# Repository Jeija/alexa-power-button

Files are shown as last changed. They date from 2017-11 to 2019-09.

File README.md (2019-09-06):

# Alexa / Dash Button = PC power button
If you like to hide your desktop computer case so that it's not in the way, you probably know that it can be quite annoying to have to press the power button in an uncomfortable location every time you want to turn on your PC. `alexa-power-button` solves this by enabling you to use both voice commands for Amazon's digital assistant "Alexa" and/or an Amazon Dash Button to start your computer.

## Hardware
`alexa-power-button` doesn't use Wake on LAN so that you can save energy by turning off all of the attached network equipment apart from a single WiFi router in your home. Instead, the only additional active device is a small ESP32-based PCB inside the computer case that can be programmed and powered using the mainboard's internal USB connectors. Most mainboards can charge phones and other USB devices while the PC is turned off, and this current is more than enough to power the ESP32. The PCB contains n-channel MOSFETs that can be used to pull the power / reset button data line low. This assumes that the power / reset button input of the mainboard consists of an active-low input pin with a positive bias voltage. This pin should then be connected to the MOSFET's drain.

The KiCad design files (schematic, PCB layout) are provided in `hardware`.

## Dash Button Setup
* Use the Amazon App to configure the dash button
* In the last step, don't select which of the products in the list to order
* Press the dash button and use wireshark or similar tools to get the button's MAC address
* In the `firmware` directory: Execute `idf.py menuconfig` and enter the Dash Button's MAC Address in `Alexa Power Button --> Dash Button MAC Address` (including colons)

After flashing the firmware, the ESP32 will capture all WiFi traffic and check if source or destination address of the IEEE 802.11 header match the provided Dash Button MAC address.

## Alexa Skill + AWS MQTT / Lambda Setup
* Follow some of the [commonly available](https://www.hackster.io/darian-johnson/diy-smart-lamp-controlled-by-toggle-switch-and-alexa-7de243) [tutorials](https://developer.amazon.com/blogs/post/Tx4WG410EHXIYQ/five-steps-before-developing-a-smart-home-skill) on how to create an Alexa Skill, set up a Lambda function and set up AWS IoT for MQTT
* Make sure to select Payload Version `v2 (legacy)` when creating the Alexa Skill
* Upload the Lambda function. If you have the AWS CLI set up, you can use the Makefile provided in `aws` to upload and test the code.
* Add `THING_ENDPOINT` (AWS IoT HTTPS REST API endpoint host, see the thing's Interact page in AWS IoT) and `MQTT_BASE_TOPIC` (prefix for MQTT topic, e.g. `myhome/mypc`) as environment variables for the Lambda function
* Get your device private key and device certificate from AWS IoT and copy them to `firmware/main/certs` as `private.pem.key` and `certificate.pem.crt` respectively. See [esp-idf's AWS IoT documentation](https://github.com/espressif/esp-idf/tree/master/examples/protocols/aws_iot) for details.
* Confgiure the firmware: Run `idf.py menuconfig` in `firmware` and add your WiFi SSID and password in `Alexa Power Button`. Configure your (arbitrary but unique) AWS IoT Client ID and add the same MQTT base topic as specified in your Lambda function environment variable. Under `Component Config --> Amazon Web Services IoT Platform`, add your AWS IoT HTTPS REST API endpoint host, see the thing's Interact page on AWS IoT.
* Flash the firmware. If errors occur while connecting to AWS IoT, see [the documentation in esp-idf](https://github.com/espressif/esp-idf/tree/master/examples/protocols/aws_iot) for some common problems.

## Flash the firmware
* Use `idf.py menuconfig` in `firmware` to configure your python executable, serial port and flasher baud rate
* `alexa-power-button` uses the usual esp-idf CMake build system and workflow. Run `idf.py all` and `idf.py flash` in `firmware` in order to compile and flash the firmware to your ESP32 board.

## Attribution
* ESP32 schematic symbol and footprint: [adamjvr's ESP32-kiCAD-Footprints
](https://github.com/adamjvr/ESP32-kiCAD-Footprints)
* Alexa Skill Lambda function validation (`aws/validation.js`): [Amazon's alexa-smarthome-validation](https://github.com/alexa/alexa-smarthome-validation)
* ESP32 code: Roughly based on esp-idf's [AWS IoT Subscribe/Publish Example](https://github.com/espressif/esp-idf/tree/master/examples/protocols/aws_iot/subscribe_publish)

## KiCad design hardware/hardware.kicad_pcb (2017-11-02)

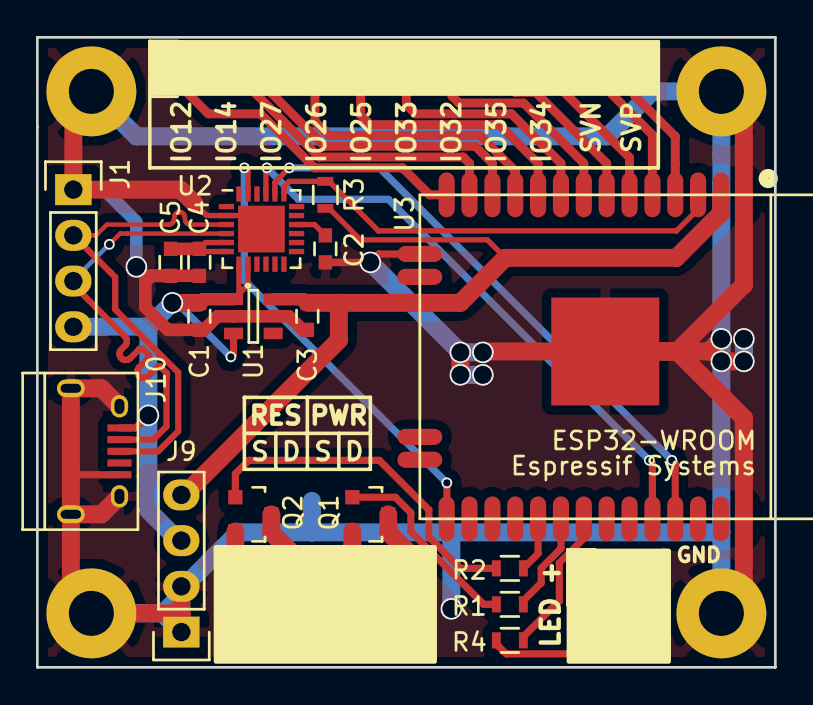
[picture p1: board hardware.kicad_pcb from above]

Board: 2 copper layers, 41.0 x 35.0 mm, 24 parts (0 on the bottom side), 33 nets.

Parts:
C1, C3: 1u; C_0603
C2, C4: 4.7u; C_0603
C5: 100n; C_0603
J1: USB; Pin_Header_Straight_1x04
J2: PWRLED; Pin_Header_Straight_1x02
J3: GPIO; Pin_Header_Straight_1x11
J4, J7: PWRSW; Pin_Header_Straight_2x01
J5, J8: RSTSW; Pin_Header_Straight_2x01
J6: PWRLED; Pin_Header_Straight_2x01
J9: Conn_01x04; Pin_Header_Straight_1x04
J10: USB_OTG; USB_Micro-B
Q1, Q2: IRLML 6344; SOT-23
R1, R2: 1K; R_0603
R3: 12K; R_0603
R4: 10K; R_0603
U1: TLV70033; SOT-23-5
U2: CP2104; QFN-24-1EP_4x4mm_Pitch0.5mm
U3: ESP32-WROOM

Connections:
+3V3: C3.1, J9.4, R3.1, U1.5, U3.2
+5V: C1.1, J1.4, J9.3, J10.1, U1.1, U1.3, U2.7, U2.8
/ESP_EN: R3.2, U2.19, U3.3
/ESP_RXD: U2.21, U3.34
/ESP_TXD: U2.20, U3.35
/PWRLED: R4.1, U3.31
/PWRSW: R1.2, U3.30
/RSTSW: R2.2, U3.29
/USB_D+: J1.2, J10.3, U2.3
/USB_D-: J1.3, J10.2, U2.4
/~ESP_FLASH: U2.23, U3.25
GND: C1.2, C2.2, C3.2, C4.2, C5.2, J1.1, J9.1, J9.2, J10.5, J10.6, U1.2, U2.2, U2.25, U3.1, U3.15, U3.38, U3.39
unnamed: C2.1, U2.16
unnamed: C4.1, C5.1, U2.5, U2.6
unnamed: J2.1, J6.2, R4.2
unnamed: J2.2, J6.1
unnamed: J3.1, U3.14
unnamed: J3.2, U3.13
unnamed: J3.3, U3.12
unnamed: J3.4, U3.11
unnamed: J3.5, U3.10
unnamed: J3.6, U3.9
unnamed: J3.7, U3.8
unnamed: J3.8, U3.7
unnamed: J3.9, U3.6
unnamed: J3.10, U3.5
unnamed: J3.11, U3.4
unnamed: J4.1, J7.2, Q1.2
unnamed: J4.2, J7.1, Q1.3
unnamed: J5.1, J8.2, Q2.2
unnamed: J5.2, J8.1, Q2.3
unnamed: Q1.1, R1.1
unnamed: Q2.1, R2.1

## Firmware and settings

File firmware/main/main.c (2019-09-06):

#include <stdio.h>
#include <stdlib.h>
#include <ctype.h>
#include <unistd.h>
#include <limits.h>
#include <string.h>

#include <freertos/FreeRTOS.h>
#include <freertos/task.h>
#include <freertos/event_groups.h>
#include <esp_event_loop.h>
#include <esp_system.h>
#include <nvs_flash.h>
#include <esp_wifi.h>
#include <esp_log.h>
#include <lwip/sockets.h>
#include <lwip/dns.h>
#include <driver/gpio.h>

#include <aws_iot_mqtt_client_interface.h>
#include <aws_iot_version.h>
#include <aws_iot_config.h>
#include <aws_iot_log.h>

/*
 * GPIO configuration
 * RSTSW_GPIO: (Output) Pin that the gate of the reset switch n-channel MOSFET is connected to
 * PWRSW_GPIO: (Output) Pin that the gate of the power switch n-channel MOSFET is connected to
 * The positive voltage-biased power / reset switch connector of the mainboard should be connected
 * to the respective n-channel MOSFET's drain while the respective ground connector should be connected
 * to the MOSFET's source. Use a multimeter to check which of your mainboard's power / reset switch pins
 * is tied to ground and which one is the active-low input.
 * These pins are used to turn on / turn off / reset the computer.
 * PWRLED_GPIO: (Input) Pin that the power led indicator of the mainboard is connected to
 * This pin is used to get the computer's power status.
 */
#define RSTSW_GPIO 5
#define PWRSW_GPIO 18
#define PWRLED_GPIO 19

/*
 * MQTT topics to subscribe to and process
 * MQTT_TOPIC_RST: Reset switch topic, a '1' message on this channel will pull the reset
 * switch active-low input low for a short duration (TODO: currently not implemeneted)
 * MQTT_TOPIC_PWR: Power switch topic, a '1' message on this channel will pull the power
 * switch active-low input low for a short duration
 */
#define MQTT_TOPIC_ALL CONFIG_AWS_TOPIC_BASE "/+"
#define MQTT_TOPIC_RST CONFIG_AWS_TOPIC_BASE "/reset"
#define MQTT_TOPIC_PWR CONFIG_AWS_TOPIC_BASE "/power"

/*
 * A connection sequence of an Amazon Dash Button consists of multiple data packets
 * containing the dash button's MAC address as source / destination address in the WiFi
 * header.
 * Since we don't want the power switch input to be triggered multiple times, we ignore
 * any further occurences of the dash button's MAC address after the first occurence for
 * DASH_UNBLOCK_TIMEOUT milliseconds.
 */
#define DASH_UNBLOCK_TIMEOUT 10000

static const char *TAG = "alexa-power-button";

typedef struct {
	uint8_t bytes[6];
} MACAddr;

typedef struct {
	uint8_t framectl1;
	uint8_t framectl2;
	uint16_t duration;
	MACAddr destination;
	MACAddr source;
	MACAddr bssid;
	uint16_t seqctl;
	uint8_t payload[];
} IEEE80211Header;

/* FreeRTOS event group to signal when we are connected & ready to make a request */
static EventGroupHandle_t wifi_event_group;

/* The event group allows multiple bits for each event,
   but we only care about one event - are we connected
   to the AP with an IP? */
const int CONNECTED_BIT = BIT0;

/*
 * When the Amazon Dash Button is pressed, the corresponding MAC address may appear
 * as source / destination address in the WiFi header multiple times.
 * In order to make sure that the power button is only triggered once, a global variable
 * dash_button_blocked is created that is automatically reset after DASH_UNBLOCK_TIMEOUT.
 */
bool dash_button_blocked = false;

/*
 * Certificates (root CA, thing certificate + private key) are embedded in binary
 */
extern const uint8_t aws_root_ca_pem_start[] asm("_binary_aws_root_ca_pem_start");
extern const uint8_t aws_root_ca_pem_end[] asm("_binary_aws_root_ca_pem_end");
extern const uint8_t certificate_pem_crt_start[] asm("_binary_certificate_pem_crt_start");
extern const uint8_t certificate_pem_crt_end[] asm("_binary_certificate_pem_crt_end");
extern const uint8_t private_pem_key_start[] asm("_binary_private_pem_key_start");
extern const uint8_t private_pem_key_end[] asm("_binary_private_pem_key_end");

static esp_err_t event_handler(void *ctx, system_event_t *event) {
	switch(event->event_id) {
	case SYSTEM_EVENT_STA_START:
		esp_wifi_connect();
		break;
	case SYSTEM_EVENT_STA_GOT_IP:
		xEventGroupSetBits(wifi_event_group, CONNECTED_BIT);
		break;
	case SYSTEM_EVENT_STA_DISCONNECTED:
		/* This is a workaround as ESP32 WiFi libs don't currently
		   auto-reassociate. */
		esp_wifi_connect();
		xEventGroupClearBits(wifi_event_group, CONNECTED_BIT);
		break;
	default:
		break;
	}
	return ESP_OK;
}

/*
 * MOSFET power / reset switch
 * Emulates push-and-release of power / reset switch
 */
static void switchInit(uint8_t gpio) {
	gpio_pad_select_gpio(gpio);
	gpio_set_direction(gpio, GPIO_MODE_OUTPUT);
	gpio_set_level(gpio, 0);
}

static void switchPushAndRelease(uint8_t gpio) {
	gpio_set_level(gpio, 1);
	vTaskDelay(1000 / portTICK_RATE_MS);
	gpio_set_level(gpio, 0);
}

/*
 * MQTT message handler
 */
static void onMQTTMsg(AWS_IoT_Client *pClient, char *topic, uint16_t topic_len, IoT_Publish_Message_Params *params, void *pData) {
	ESP_LOGI(TAG, "MQTT: Got message, channel \"%.*s\", content \"%.*s\"", topic_len, topic, params->payloadLen, (char *)params->payload);

	uint8_t gpio = 0;
	if (strncmp(topic, MQTT_TOPIC_RST, topic_len) == 0)
		gpio = RSTSW_GPIO;
	else if (strncmp(topic, MQTT_TOPIC_PWR, topic_len) == 0)
		gpio = PWRSW_GPIO;
	else {
		ESP_LOGW(TAG, "MQTT: Unknown topic %.*s, ignoring", topic_len, topic);
		return;
	}

	if (strncmp(params->payload, "1", params->payloadLen) == 0)
		switchPushAndRelease(gpio);
	else {
		ESP_LOGW(TAG, "MQTT: Unknown content %.*s, ignoring", params->payloadLen, (char *) params->payload);
		return;
	}	
}

// Client should auto-reconnect, nothing to do here
static void onMQTTDisconnect(AWS_IoT_Client *pClient, void *data) {
	ESP_LOGW(TAG, "MQTT: Disconnected, auto-reconnecting");
}

static void MQTTPublish(AWS_IoT_Client *client, char *topic, char *msg) {
	IoT_Publish_Message_Params publishParams;
	publishParams.qos = QOS0;
	publishParams.payload = msg;
	publishParams.payloadLen = strlen(msg);
	publishParams.isRetained = 0;
	aws_iot_mqtt_publish(client, topic, strlen(topic), &publishParams);
}

/*
 * Connect to Amazon AWS IoT
 * and subscribe to relevant MQTT topics
 */
static void mqtt_task(void *param) {
	IoT_Error_t rc = FAILURE;

	ESP_LOGI(TAG, "MQTT: AWS IoT SDK Version %d.%d.%d-%s", VERSION_MAJOR, VERSION_MINOR, VERSION_PATCH, VERSION_TAG);

	/*
	 * Initialize MQTT client with remote host + port and crypto
	 */
	IoT_Client_Init_Params mqttInitParams = iotClientInitParamsDefault;
	mqttInitParams.enableAutoReconnect = false; // We enable this later below
	mqttInitParams.pHostURL = AWS_IOT_MQTT_HOST;
	mqttInitParams.port = AWS_IOT_MQTT_PORT;
	mqttInitParams.pRootCALocation = (const char *)aws_root_ca_pem_start;
	mqttInitParams.pDeviceCertLocation = (const char *)certificate_pem_crt_start;
	mqttInitParams.pDevicePrivateKeyLocation = (const char *)private_pem_key_start;
	mqttInitParams.mqttCommandTimeout_ms = 20000;
	mqttInitParams.tlsHandshakeTimeout_ms = 5000;
	mqttInitParams.isSSLHostnameVerify = true;
	mqttInitParams.disconnectHandler = onMQTTDisconnect;
	mqttInitParams.disconnectHandlerData = NULL;

	AWS_IoT_Client client;
	rc = aws_iot_mqtt_init(&client, &mqttInitParams);
	if (SUCCESS != rc) {
		ESP_LOGE(TAG, "MQTT: aws_iot_mqtt_init returned error : %d ", rc);
		abort();
	}

	/*
	 * Wait for WiFi Connection
	 */
	ESP_LOGI(TAG, "MQTT: Waiting for WiFi connection before attempting to connect to AWS IoT...");
	xEventGroupWaitBits(wifi_event_group, CONNECTED_BIT, false, true, portMAX_DELAY);

	/*
	 * Connect to AWS IoT
	 */
	IoT_Client_Connect_Params connectParams = iotClientConnectParamsDefault;
	connectParams.keepAliveIntervalInSec = 10;
	connectParams.pClientID = CONFIG_AWS_CLIENT_ID;
	connectParams.clientIDLen = (uint16_t) strlen(CONFIG_AWS_CLIENT_ID);

	ESP_LOGI(TAG, "MQTT: Connecting to AWS IoT...");
	do {
		rc = aws_iot_mqtt_connect(&client, &connectParams);
		if (SUCCESS != rc) {
			ESP_LOGE(TAG, "MQTT: Error(%d) connecting to %s:%d", rc, mqttInitParams.pHostURL, mqttInitParams.port);
			vTaskDelay(1000 / portTICK_RATE_MS);
		}
	} while(SUCCESS != rc);

	/*
	 * Enable Auto Reconnect functionality.
	 */
	rc = aws_iot_mqtt_autoreconnect_set_status(&client, true);
	if (SUCCESS != rc) {
		ESP_LOGE(TAG, "MQTT: Unable to set Auto Reconnect to true - %d", rc);
		abort();
	}

	/*
	 * Subscribe to all relevant topics
	 */
	ESP_LOGI(TAG, "MQTT: Subscribing to %s", MQTT_TOPIC_ALL);

	rc = aws_iot_mqtt_subscribe(&client, MQTT_TOPIC_ALL, strlen(MQTT_TOPIC_ALL), QOS0, onMQTTMsg, NULL);
	if(SUCCESS != rc) {
		ESP_LOGE(TAG, "MQTT: Error subscribing: %d ", rc);
		abort();
	}

	/*
	 * Wait for incoming MQTT messages
	 */
	while ((NETWORK_ATTEMPTING_RECONNECT == rc || NETWORK_RECONNECTED == rc || SUCCESS == rc)) {
		ESP_LOGI(TAG, "MQTT: Waiting for messages...");
		rc = aws_iot_mqtt_yield(&client, 3000);
	}

	ESP_LOGE(TAG, "MQTT: Terminated unexpectedly");
	abort();
}

/*
 * Amazon Dash Button handlers
 * Including some MAC address utilities
 */
static bool compareMACAddress(MACAddr mac1, MACAddr mac2) {
	for (uint8_t i = 0; i < 6; ++i)
		if (mac1.bytes[i] != mac2.bytes[i])
			return false;

	return true;
}

static void macAddrFromString(MACAddr *target, char *macstring) {
	char macstring_copy[18];
	memcpy(macstring_copy, macstring, 18);

	// Replace ':' with '\0' and check format
	for (uint8_t i = 0; i < 5; ++i) {
		if (macstring_copy[2 + i * 3] != ':') {
			ESP_LOGE(TAG, "DASH: Dash Button MAC Address invalid");
		} else {
			macstring_copy[2 + i * 3] = '\0';
		}
	}

	// Convert hex string to MACAddr
	for (uint8_t i = 0; i < 6; ++i)
		target->bytes[i] = strtol(&macstring_copy[i * 3], NULL, 16);
}

static void dashUnblockTimeout(TimerHandle_t xTimer) {
	dash_button_blocked = false;
}

/*
 * Sniff all WiFi traffic and watch out for the dash button's MAC address
 * as destination / source address in IEEE 802.11 header.
 */
static void dashButtonSniffer(void* buf, wifi_promiscuous_pkt_type_t type) {
	if (type == WIFI_PKT_DATA) {
		// Interpret buffer payload as IEEE 802.11 header
		IEEE80211Header *header = (IEEE80211Header*)(((wifi_promiscuous_pkt_t*)buf)->payload);

		// Compare IEEE 802.11 source and destination addresses with Dash Button MAC
		MACAddr dashMAC;
		macAddrFromString(&dashMAC, CONFIG_DASH_BUTTON_MAC);
		if ((compareMACAddress(header->source, dashMAC) || compareMACAddress(header->destination, dashMAC)) && !dash_button_blocked) {
			ESP_LOGI(TAG, "Amazon Dash Button press registered");
			dash_button_blocked = true;
			TimerHandle_t unblock_timer = xTimerCreate("dashUnblockTimeout", DASH_UNBLOCK_TIMEOUT / portTICK_RATE_MS, false, NULL, dashUnblockTimeout);
			xTimerStart(unblock_timer, 0);
			switchPushAndRelease(PWRSW_GPIO);
		}
	}
}

static void wifi_init() {
	nvs_flash_init();

	/*
	 * Standard WiFi connection setup
	 */
	tcpip_adapter_init();
	wifi_event_group = xEventGroupCreate();
	ESP_ERROR_CHECK(esp_event_loop_init(event_handler, NULL));
	wifi_init_config_t cfg = WIFI_INIT_CONFIG_DEFAULT();
	ESP_ERROR_CHECK(esp_wifi_init(&cfg));
	ESP_ERROR_CHECK(esp_wifi_set_storage(WIFI_STORAGE_RAM));
	wifi_config_t wifi_config = {
		.sta = {
			.ssid = CONFIG_WIFI_SSID,
			.password = CONFIG_WIFI_PASSWORD,
		},
	};
	ESP_ERROR_CHECK(esp_wifi_set_mode(WIFI_MODE_STA));
	ESP_ERROR_CHECK(esp_wifi_set_config(WIFI_IF_STA, &wifi_config));
	ESP_ERROR_CHECK(esp_wifi_start());

	/*
	 * Enable packet sniffer for WiFi header MAC address detection for Amazon Dash Button
	 */
	const wifi_promiscuous_filter_t filt = {
		.filter_mask = WIFI_PROMIS_FILTER_MASK_DATA | WIFI_PROMIS_FILTER_MASK_MGMT
	};

	ESP_ERROR_CHECK(esp_wifi_set_promiscuous(true));
	ESP_ERROR_CHECK(esp_wifi_set_promiscuous_filter(&filt));
	ESP_ERROR_CHECK(esp_wifi_set_promiscuous_rx_cb(&dashButtonSniffer));
}

void app_main() {
	wifi_init();
	switchInit(PWRSW_GPIO);
	switchInit(RSTSW_GPIO);
	xTaskCreatePinnedToCore(&mqtt_task, "mqtt_task", 36 * 1024, NULL, 5, NULL, 1);
}
